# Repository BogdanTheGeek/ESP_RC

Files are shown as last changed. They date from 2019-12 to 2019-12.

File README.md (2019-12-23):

# ESP_RC
An Open-Source Transmitter/Receiver for RC Planes, Cars, Boats and more based on the ESP8266 and ESP32 family of devices

## Operation

The ESP_RC project is based on the functionality of the ESP8266 and ESP32 use p2p comunication though Wi-fi 802.11n without the use of TCP or UDP. This is called ESP-Now and drastically reduces the latency of the transmission enableing real time control of RC vehicles.The two devices are linked together through their MAC address. The receiver sends telemetry to the transmitter and the transmitter sends controls back. The packet size is limited to 250 Bytes.
Current reciever designs are:
smol_boy_V1	
ESP8266 6-CH receiver with Battery voltage monitoring and I2C peripherals for more telemetry

There are no designs yet for a transmitter however there is a Linux Project that allows Direct comunication through ESP-Now from a PC. This might come in handy:
https://github.com/thomasfla/Linux-ESPNOW
The first working transmitter will hopefully be able to use a buetooth controller. From my research, the xbox one s controller is a bit tricky but the PS3 controller has a ESP-IDF library available here:
https://github.com/jvpernis/esp32-ps3
In the future we might want to build a custom controller with maybe even an LCD screen, accelerometer and so on.

## Features 
 - [x] Built in baterry voltage telemetry
 - [x] I2C expansion port telemetry
 - [x] Bluetooth controller support for ESP32
 - [ ] GPS support
 - [ ] Multiple vehicle profiles configurable via AP
 - [ ] Easy vehicle controls setup via AP
 - [ ] Return to home mode (GPS)
 - [ ] Flight-controller features?

## Supported I2C devices
| Support			| Name			| Description													|
|---|---|---|
|:heavy_check_mark:	| BMP280 		| Temp, Altitude, Pressure										|
|:white_check_mark:	| MPU-6050		| Gyro, Acceleremeter											|
|:white_check_mark:	| LSM303D		| Compass, 3D accelerometer and 3D magnetometer module			|
|:white_check_mark:	| MPU-9250		| Gyro, Accelerometer + AK8963 magnetometer						|
|:white_check_mark:	| HMC5883		| Magnetomer													|
|:white_check_mark:	| ITG-3200		| 'Gaming' gyro													|
|:white_check_mark:	| INA219		| Bi-directional current meter									|
|:white_check_mark:	| Wii IR Sensor	| Tracks the 4 brighest IR Points in FOV (Missile tracking?)	|
|:white_check_mark:	| ZOE/SAM-M8Q	| GPS module													|
|:white_check_mark:	| XA1110		| GPS module													|
|:white_check_mark:	| LSM9DS1		| Gyro, Accelerometer, magnetometer								|
|:white_check_mark:	| ADS1115		| 4-CH ADC														|
|:white_check_mark:	| 24LC256		| EEPROM														|

## Credit

WifiEspNow library : https://github.com/yoursunny/WifiEspNow
ESP32-PS3 library : https://github.com/jvpernis/esp32-ps3/tree/develop
Espressif in their holyness.

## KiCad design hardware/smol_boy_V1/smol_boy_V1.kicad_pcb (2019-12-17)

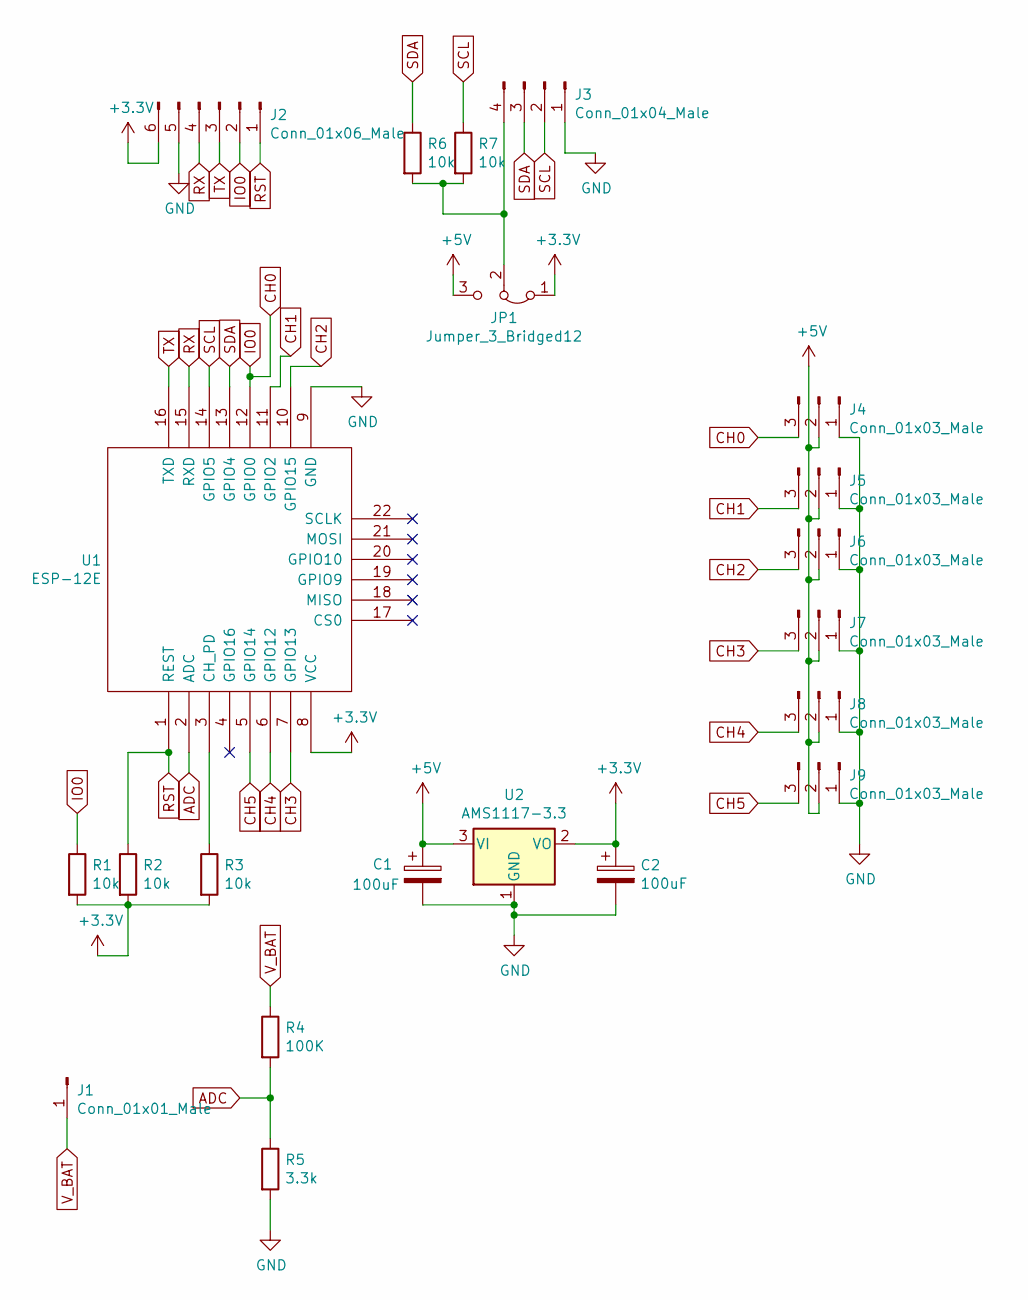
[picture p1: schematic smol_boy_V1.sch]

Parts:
C1, C2: 100uF; CP_EIA-7343-31_Kemet-D_Pad2.25x2.55mm_HandSolder
J1: Conn_01x01_Male; PinHeader_1x01_P2.54mm_Vertical
J2: Conn_01x06_Male; PinHeader_1x06_P2.54mm_Vertical
J3: Conn_01x04_Male; PinHeader_1x04_P2.54mm_Vertical
J4, J5, J6, J7, J8, J9: Conn_01x03_Male; PinHeader_1x03_P2.54mm_Vertical
JP1: Jumper_3_Bridged12; SolderJumper-3_P1.3mm_Open_RoundedPad1.0x1.5mm_NumberLabels
R1, R2, R3, R6, R7: 10k; R_1206_3216Metric_Pad1.42x1.75mm_HandSolder
R4: 100K; R_1206_3216Metric_Pad1.42x1.75mm_HandSolder
R5: 3.3k; R_1206_3216Metric_Pad1.42x1.75mm_HandSolder
U1: ESP-12E
U2: AMS1117-3.3; SOT-223-3_TabPin2

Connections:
+3V3: C2.1, J2.6, JP1.1 (A), R1.2, R2.2, R3.2, U1.8 (VCC), U2.2 (VO)
+5V: C1.1, J4.2, J5.2, J6.2, J7.2, J8.2, J9.2, JP1.3 (B), U2.3 (VI)
ADC: R4.2, R5.1, U1.2 (ADC)
CH0: J2.2, J4.3, R1.1, U1.12 (GPIO0)
CH1: J5.3, U1.11 (GPIO2)
CH2: J6.3, U1.10 (GPIO15)
CH3: J7.3, U1.7 (GPIO13)
CH4: J8.3, U1.6 (GPIO12)
CH5: J9.3, U1.5 (GPIO14)
GND: C1.2, C2.2, J2.5, J3.1, J4.1, J5.1, J6.1, J7.1, J8.1, J9.1, R5.2, U1.9 (GND), U2.1 (GND)
unnamed: J3.4, JP1.2 (C), R6.2, R7.2
unnamed: R3.1, U1.3 (CH_PD)
RST: J2.1, R2.1, U1.1 (REST)
RX: J2.4, U1.15 (RXD)
SCL: J3.2, R7.1, U1.14 (GPIO5)
SDA: J3.3, R6.1, U1.13 (GPIO4)
TX: J2.3, U1.16 (TXD)
V_BAT: J1.1, R4.1

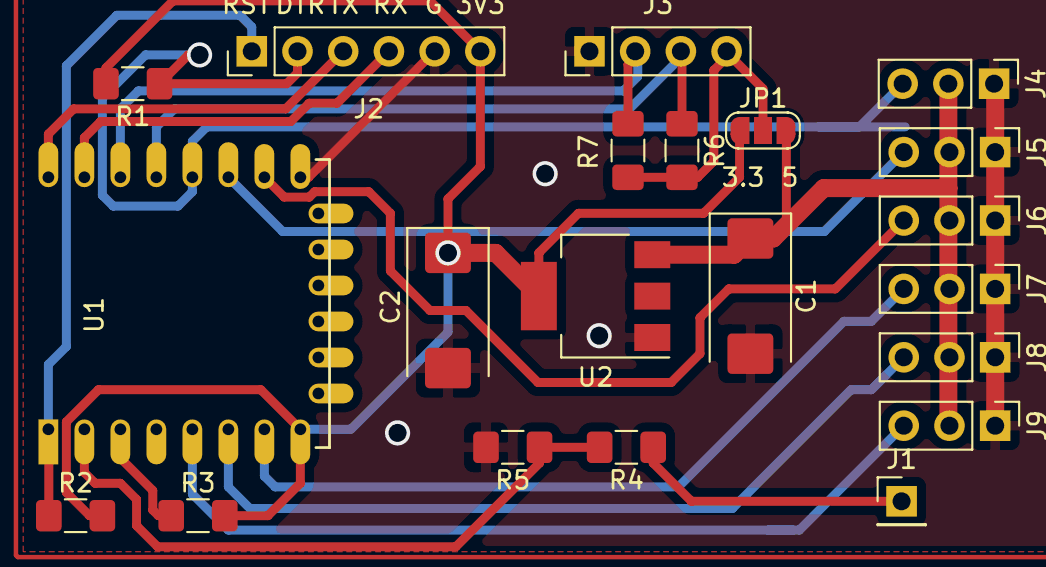
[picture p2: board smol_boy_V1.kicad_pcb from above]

Board: 2 copper layers, 21 parts (0 on the bottom side), 18 nets.

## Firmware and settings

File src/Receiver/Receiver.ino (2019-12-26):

#include "libs.h"

const int channel_map[6] = {CH0, CH1, CH2, CH3, CH4, CH5};
Channel *channel[6];

NowConnection *connection;

typedef struct {
	uint8_t ch0_pos;
	uint8_t ch1_pos;
	uint8_t ch2_pos;
	uint8_t ch3_pos;
	uint8_t ch4_pos;
	uint8_t ch5_pos;

}CONTROLS;

CONTROLS position_data;
char* in;

void setup() {

	for (int i = 0; i < 6; ++i)
	{
	channel[i] = new Channel(channel_map[i]);
	}

	#if defined(DEBUG_OUT)
	Serial.begin(9600);
	#endif

	connection = new NowConnection();
	delay(500);

	#if defined(DEBUG_OUT)
	String mac = connection->my_mac();
	Serial.println("My MAC:");
	Serial.println(mac);
	#endif


	in = connection->get_pkt_in();

}

void loop() {
	memcpy(&position_data, in, sizeof(in));

	channel[0]->set(position_data.ch0_pos);
	channel[1]->set(position_data.ch1_pos);
	channel[2]->set(position_data.ch2_pos);
	channel[3]->set(position_data.ch3_pos);
	channel[4]->set(position_data.ch4_pos);
	channel[5]->set(position_data.ch5_pos);
}

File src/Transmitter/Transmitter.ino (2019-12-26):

#include "libs.h" 

NowConnection *connection;
Controller *controller;

CONTROLS channels_pos;
char* out;

void setup(){

	#if defined(DEBUG_OUT)
	Serial.begin(9600);
	#endif
	connection = new NowConnection();
	controller = new Controller(&channels_pos, 0);
	delay(500);

	#if defined(DEBUG_OUT)
	String mac = connection->my_mac();
	Serial.println("My MAC:");
	Serial.println(mac);
	#endif

	out = connection->get_pkt_out();

}

void loop(){

	memcpy(out, &channels_pos, sizeof(channels_pos));
  	connection->send(sizeof(channels_pos));
  	#if defined(DEBUG_OUT)
  	Serial.println("Sent");
  	#endif
	
	delay(50);

}

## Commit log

2019-12-11 layed down the foundation, support for telemetry communinations and different boards
    [Configuration.h]
2019-12-11 updated readme for supported i2c devices
2019-12-11 more i2c devices added
2019-12-11 fixed resistor for v_Bat from 10k to 3.3k as adc range is only 0-1v for 12e module
2019-12-13 tranmitter implemented
    [Configuration.h]
2019-12-13 DEBUG compilation option
    [Configuration.h]
2019-12-13 debug enabled for tX
    [Configuration.h]
2019-12-13 fixed comp errors
    [Configuration.h]
2019-12-13 forgot one print statement
2019-12-17 fixed pcb channel pins
    [smol_boy_V1.kicad_pcb, smol_boy_V1.sch]
2019-12-17 first working communication test
    [Configuration.h]
2019-12-17 pcb pullups fixed
    [smol_boy_V1.sch]
2019-12-26 first working prototype
    [Configuration.h]
